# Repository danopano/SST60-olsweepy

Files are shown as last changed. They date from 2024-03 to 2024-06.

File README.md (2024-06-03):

# SST60-olsweepy
This repo is a fork and mod of dededecline/SST60! Below renders are from his original design.  
The provided production files cover daughterboard variants with and without flex cuts.  
Kicad 8.0 is recommended, with the JLC PCB plugin installed.  

## Fully open source multi-layout 60% PCB
Render1
Render2
<sub> renders outdated, using the old outline. </sub>

## Layout support
KLE

## Features
- RGB Underglow
- RP2040 processor
- MX and Alps compatible
- Indicator light positions for Caps Lock and Esc
- Standard tray mount support
- Gummy O-Ring support (Bakenko, ogre, etc. anything that h60 supports, this does too.)
- USB-C or Unified Daughterboard (or equivalent with the same pinout)
- Overcurrent and ESD protection
- Flex meme cuts

## ***DISCLAIMER***
Note: the below claim is not yet applicable for this fork.
This PCB has been tested and confirmed to work properly. The members of the PCB development team are not liable if you end up with a non-functional pcb. Order at your own risk. Support will not be provided but pull requests will be reviewed and possibly accepted.

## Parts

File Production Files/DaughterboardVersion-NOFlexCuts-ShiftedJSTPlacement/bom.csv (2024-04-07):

Designator | Footprint | Quantity | Value | LCSC Part #
C_1V-Decoup1, C_3V-Decoup2, C_LDO1, C_LDO2 | 0402 | 4 | 1u
C_1V-Decoup2, C_1V-Decoup3, C_3V-Decoup3, C_3V-Decoup4, C_3V-Decoup5, C_3V-Decoup6, C_3V-Decoup7, C_3V-Decoup8, C_3V-Decoup9, C_Flash1 | 0402 | 10 | 100n
C_3V-Decoup1 | 0402 | 1 | 10u
C_Crystal1, C_Crystal2 | 0402 | 2 | 22pF
C_Shield1 | 0402 | 1 | 4.7n
D1, D10, D11, D12, D13, D14, D15, D16, D17, D18, D19, D2, D20, D21, D22, D23, D25, D26, D27, D28, D3, D30, D31, D32, D33, D34, D35, D36, D37, D38, D39, D4, D40, D41, D42, D43, D44, D45, D46, D48, D49, D5, D50, D51, D53, D54, D55, D56, D57, D58, D59, D6, D61, D62, D63, D64, D65, D66, D67, D68, D7, D8 | D_SOD-123 | 62 | 1N4148
D69, D70, D71, D72, D73, D74, D75, D76, D77, D78, D79, D80, D81, D82, D83, D84 | LED_WS2812_2020 | 16 | WS2812B-2020
F1 | 0805 | 1 | 500mA
J1 | JST_SH_SM04B-SRSS-TB_1x04-1MP_P1.00mm_Horizontal | 1 | SM04B-SRSS-TB(LF)(SN)
R_Crystal1, R_Flash1, R_RST1 | 0402 | 3 | 1k
R_DATA1, R_DATA2 | 0402 | 2 | 27
R_LED1, R_LED2 | 0402 | 2 | 220
R_Shield1 | 0402 | 1 | 1M
SW1, SW2 | SW_SPST_TL3342 | 2 | TL3342F450QG
U1 | RP2040-QFN-56 | 1 | RP2040
U2 | SOIC-8_5.23x5.23mm_P1.27mm | 1 | W25Q128JVS
U3 | SOT-23 | 1 | XC6206PxxxMR
U4 | SOT143B | 1 | PRTR5V0U2X
U5 | SOT-23-5 | 1 | 74AHCT1G125
Y1 | Crystal_SMD_3225-4Pin_3.2x2.5mm | 1 | 12MHz

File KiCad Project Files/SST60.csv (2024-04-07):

Id | Designator | Footprint | Quantity | Designation | Supplier and ref
1 | MX7,MX4,MX62,MX17,MX74,MX76 | MXOnly-1.5U-NoLED | 6 | MX-NoLED
2 | MX28,MX59,MX23,MX50,MX15,MX36,MX35,MX20,MX39,MX16,MX75,MX14,MX58,MX30,MX21,MX67,MX27,MX29,MX55,MX43,MX54,MX9,MX8,MX34,MX64,MX47,MX56,MX25,MX19,MX10,MX73,MX53,MX49,MX44,MX46,MX61,MX24,MX12,MX40,MX18,MX33,MX60,MX63,MX69,MX45,MX13,MX37,MX48,MX22,MX38 | MXOnly-1U-NoLED | 50 | MX-NoLED
3 | MX1 | MXOnly-1.25U | 1 | MX-LED
4 | MX66 | MXOnly-1.75U-NoLED | 1 | MX-NoLED
5 | H1 | L60 Outline | 1 | PCB Outline
6 | MX70,MX6 | MXOnly-2.25U-NoLED | 2 | MX-NoLED
7 | MX3 | MXOnly-1U | 1 | MX-LED
8 | MX42 | MXOnly-7U-ReversedStabilizers-NoLED | 1 | MX-NoLED
9 | U4 | SOT143B | 1 | PRTR5V0U2X
10 | SW2 | SW_SPST_TL3342 | 1 | Reset
11 | D19,D46,D15,D63,D35,D26,D54,D34,D50,D48,D22,D40,D14,D10,D61,D37,D39,D2,D6,D1,D67,D13,D21,D4,D3,D36,D12,D25,D30,D51,D28,D38,D45,D32,D55,D49,D5,D23,D20,D42,D64,D65,D16,D56,D27,D59,D58,D57,D43,D68,D66,D62,D18,D33,D8,D44,D53,D7,D31,D11,D41,D17 | D_SOD-123 | 62 | D_Small
12 | C_3V-Decoup8,C_1V-Decoup2,C_Flash1,C_3V-Decoup6,C_3V-Decoup7,C_3V-Decoup4,C_3V-Decoup5,C_3V-Decoup3,C_1V-Decoup3,C_3V-Decoup9 | C_0402_1005Metric | 10 | .1u
13 | D74,D71,D84,D78,D77,D72,D75,D76,D79,D70,D82,D81,D73,D83,D80,D69 | LED_WS2812_2020 | 16 | WS2812B-2020
14 | C_LDO2,C_3V-Decoup2,C_1V-Decoup1,C_LDO1 | C_0402_1005Metric | 4 | 1u
15 | C_Crystal2,C_Crystal1 | C_0402_1005Metric | 2 | 22pF
16 | R_Crystal1,R_RST1,R_Flash1 | R_0402_1005Metric | 3 | 1k
17 | R_LED1,R_LED2 | R_0402_1005Metric | 2 | 220
18 | USB1 | HRO-TYPE-C-31-M-12-Assembly | 1 | HRO-TYPE-C-31-M-12
19 | U1 | RP2040-QFN-56 | 1 | RP2040
20 | J2 | PinHeader_1x05_P2.54mm_Vertical | 1 | SWD
21 | R_DATA2,R_DATA1 | R_0402_1005Metric | 2 | 27
22 | R_USB1,R_USB2 | R_0402_1005Metric | 2 | 5k1
23 | SW1 | SW_SPST_TL3342 | 1 | Boot
24 | J1 | JST_SH_SM04B-SRSS-TB_1x04-1MP_P1.00mm_Horizontal | 1 | SM04B
25 | R_Shield1 | R_0402_1005Metric | 1 | 1M
26 | Y1 | Crystal_SMD_3225-4Pin_3.2x2.5mm | 1 | 12MHz
27 | U5 | SOT-23-5 | 1 | 74AHCT1G125
28 | U3 | SOT-23 | 1 | XC6206PxxxMR
29 | C_Shield1 | C_0402_1005Metric | 1 | 4.7n
30 | U2 | SOIC-8_5.23x5.23mm_P1.27mm | 1 | W25Q128JVS
31 | F1 | Fuse_0805_2012Metric | 1 | 500mA
32 | C_3V-Decoup1 | C_0402_1005Metric | 1 | 10u

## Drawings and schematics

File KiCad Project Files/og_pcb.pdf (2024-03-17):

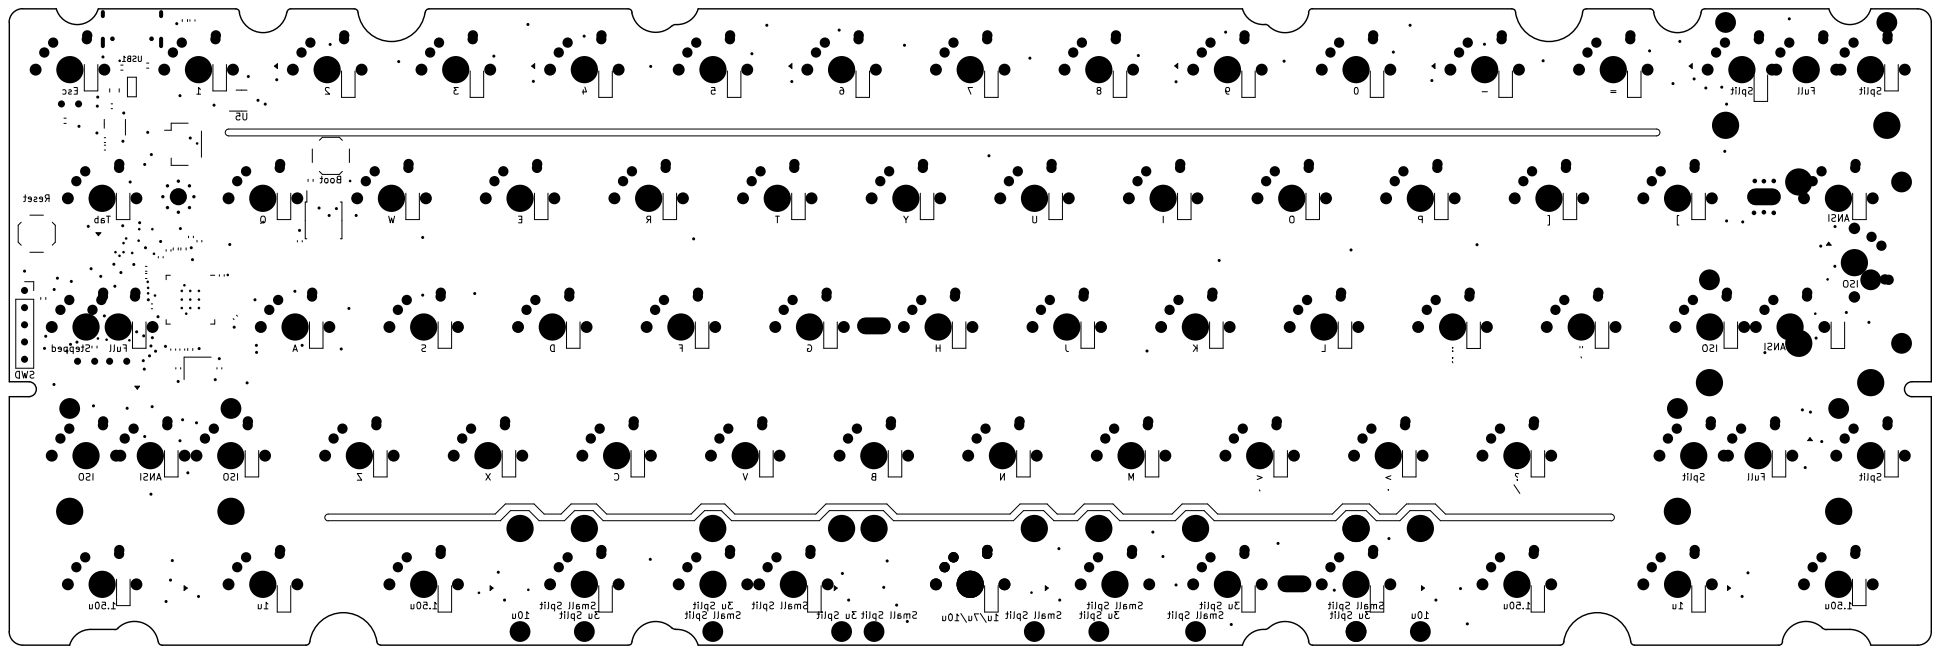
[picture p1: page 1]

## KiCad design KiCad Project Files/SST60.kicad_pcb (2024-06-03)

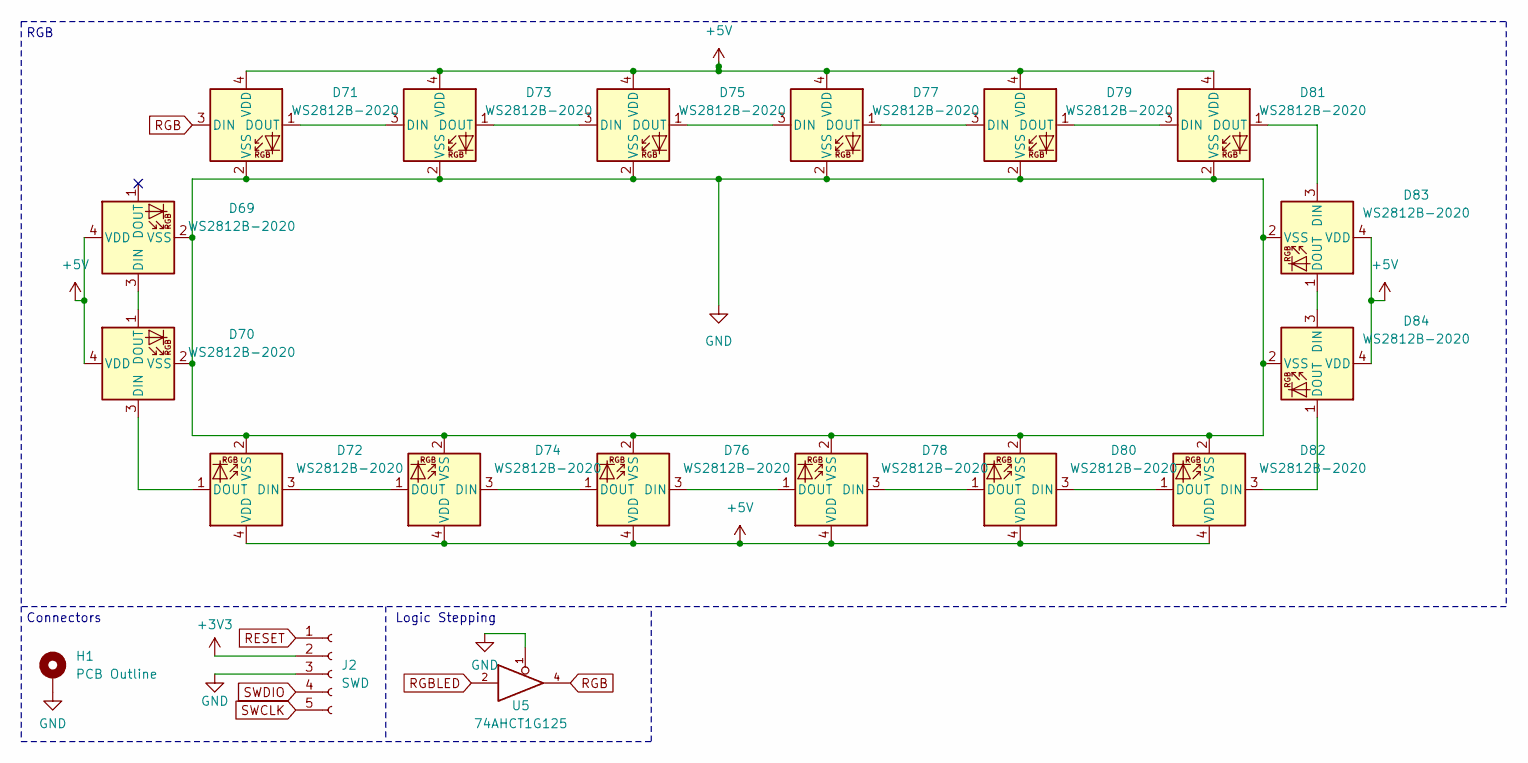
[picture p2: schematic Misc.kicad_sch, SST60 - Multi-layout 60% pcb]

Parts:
D69, D70, D71, D72, D73, D74, D75, D76, D77, D78, D79, D80, D81, D82, D83, D84: WS2812B-2020; LED_WS2812_2020
H1: PCB Outline; L60 Outline
J2: SWD; PinHeader_1x05_P2.54mm_Vertical
U5: 74AHCT1G125; SOT-23-5

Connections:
+3V3: J2.2; also elsewhere on the board
+5V: D69.4 (VDD), D70.4 (VDD), D71.4 (VDD), D72.4 (VDD), D73.4 (VDD), D74.4 (VDD), D75.4 (VDD), D76.4 (VDD), D77.4 (VDD), D78.4 (VDD), D79.4 (VDD), D80.4 (VDD), D81.4 (VDD), D82.4 (VDD), D83.4 (VDD), D84.4 (VDD), U5.5 (+5V); also elsewhere on the board
GND: D69.2 (VSS), D70.2 (VSS), D71.2 (VSS), D72.2 (VSS), D73.2 (VSS), D74.2 (VSS), D75.2 (VSS), D76.2 (VSS), D77.2 (VSS), D78.2 (VSS), D79.2 (VSS), D80.2 (VSS), D81.2 (VSS), D82.2 (VSS), D83.2 (VSS), D84.2 (VSS), H1.1, J2.3, U5.1, U5.3 (GND); also elsewhere on the board
unnamed: D69.3 (DIN), D70.1 (DOUT)
unnamed: D70.3 (DIN), D72.1 (DOUT)
unnamed: D71.1 (DOUT), D73.3 (DIN)
unnamed: D72.3 (DIN), D74.1 (DOUT)
unnamed: D73.1 (DOUT), D75.3 (DIN)
unnamed: D74.3 (DIN), D76.1 (DOUT)
unnamed: D75.1 (DOUT), D77.3 (DIN)
unnamed: D76.3 (DIN), D78.1 (DOUT)
unnamed: D77.1 (DOUT), D79.3 (DIN)
unnamed: D78.3 (DIN), D80.1 (DOUT)
unnamed: D79.1 (DOUT), D81.3 (DIN)
unnamed: D80.3 (DIN), D82.1 (DOUT)
unnamed: D81.1 (DOUT), D83.3 (DIN)
unnamed: D82.3 (DIN), D84.1 (DOUT)
unnamed: D83.1 (DOUT), D84.3 (DIN)
RESET: J2.1; also elsewhere on the board
RGB: D71.3 (DIN), U5.4
RGBLED: U5.2; also elsewhere on the board
SWCLK: J2.5; also elsewhere on the board
SWDIO: J2.4; also elsewhere on the board

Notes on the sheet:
Logic Stepping
Connectors
RGB

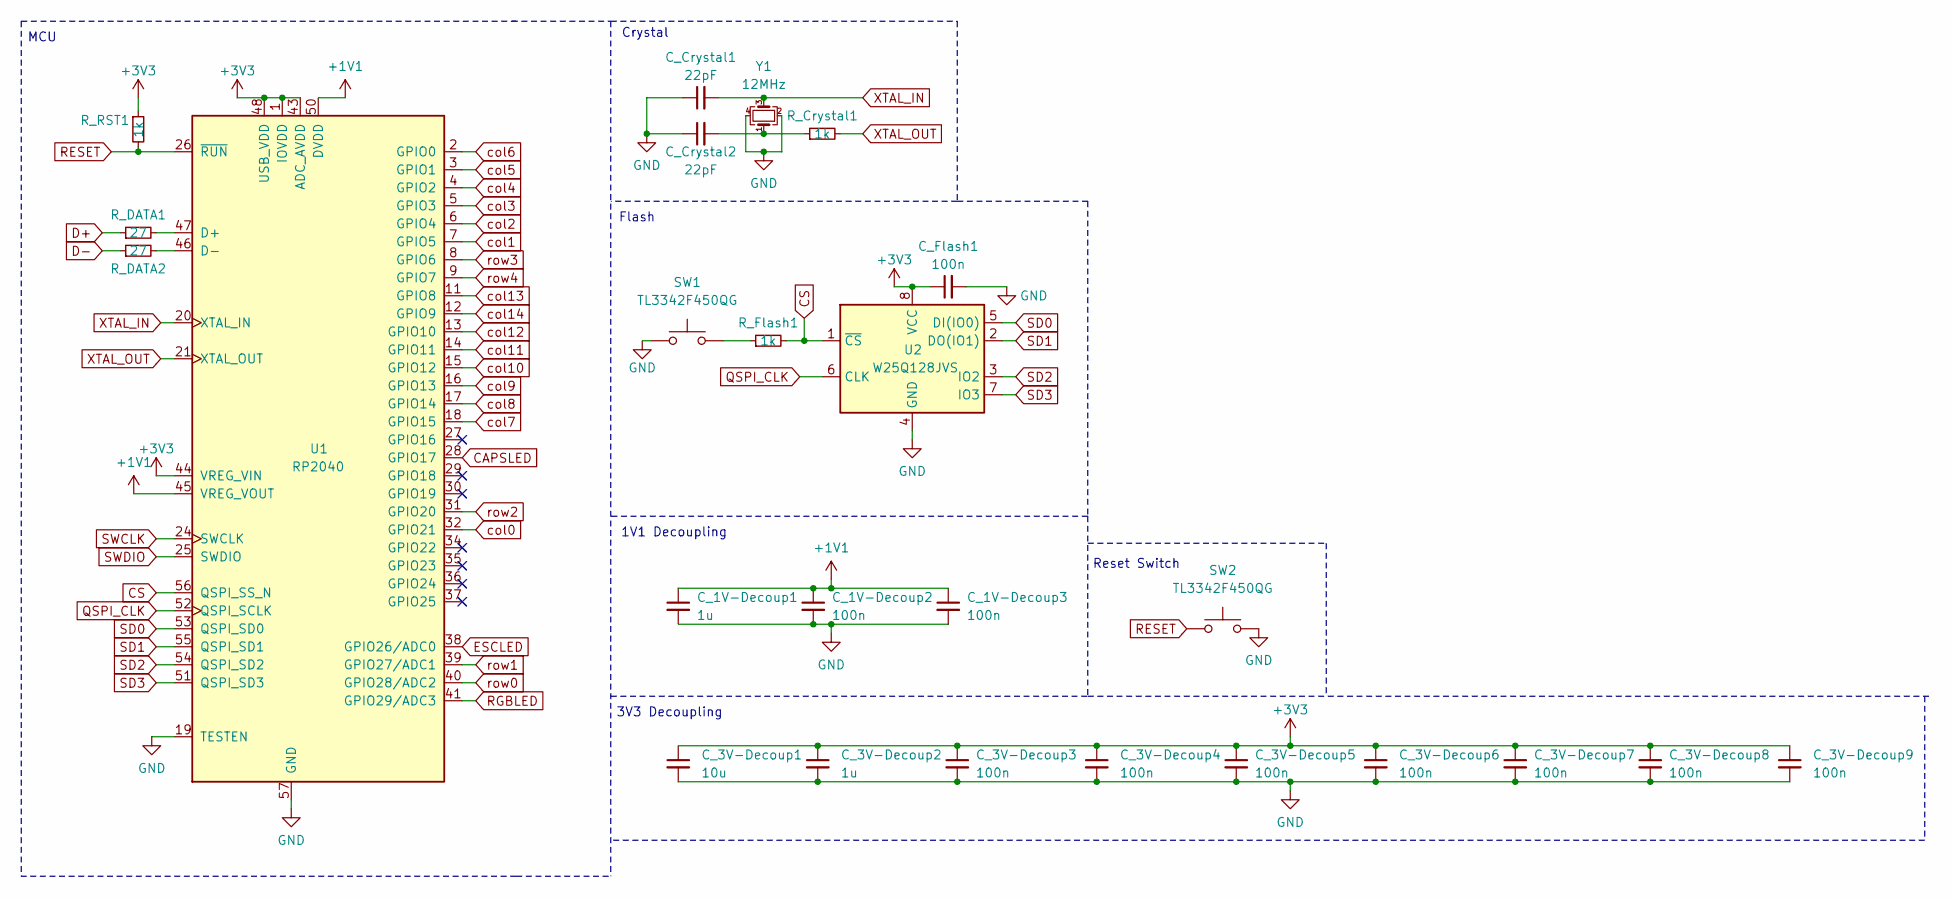
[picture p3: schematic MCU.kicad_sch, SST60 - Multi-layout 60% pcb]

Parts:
C_1V-Decoup1, C_3V-Decoup2: 1u; C_0402_1005Metric
C_1V-Decoup2, C_1V-Decoup3, C_3V-Decoup3, C_3V-Decoup4, C_3V-Decoup5, C_3V-Decoup6, C_3V-Decoup7, C_3V-Decoup8, C_3V-Decoup9: 100n; C_0402_1005Metric
C_3V-Decoup1: 10u; C_0402_1005Metric
C_Crystal1, C_Crystal2: 22pF; C_0402_1005Metric
C_Flash1: 100n; C_0402_1005Metric
R_Crystal1: 1k; R_0402_1005Metric
R_DATA1, R_DATA2: 27; R_0402_1005Metric
R_Flash1: 1k; R_0402_1005Metric
R_RST1: 1k; R_0402_1005Metric
SW1, SW2: TL3342F450QG; SW_SPST_TL3342
U1: RP2040; RP2040-QFN-56
U2: W25Q128JVS; SOIC-8_5.23x5.23mm_P1.27mm
Y1: 12MHz; Crystal_SMD_3225-4Pin_3.2x2.5mm

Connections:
+1V1: C_1V-Decoup1.1, C_1V-Decoup2.1, C_1V-Decoup3.1, U1.23 (DVDD), U1.45 (VREG_VOUT), U1.50 (DVDD)
+3V3: C_3V-Decoup1.1, C_3V-Decoup2.1, C_3V-Decoup3.1, C_3V-Decoup4.1, C_3V-Decoup5.1, C_3V-Decoup6.1, C_3V-Decoup7.1, C_3V-Decoup8.1, C_3V-Decoup9.1, C_Flash1.1, R_RST1.1, U1.1 (IOVDD), U1.10 (IOVDD), U1.22 (IOVDD), U1.33 (IOVDD), U1.42 (IOVDD), U1.43 (ADC_AVDD), U1.44 (VREG_VIN), U1.48 (USB_VDD), U1.49 (IOVDD), U2.8 (VCC); also elsewhere on the board
CAPSLED: U1.28 (GPIO17); also elsewhere on the board
CS: R_Flash1.2, U1.56 (QSPI_SS_N), U2.1 (~CS)
D+: R_DATA1.1; also elsewhere on the board
D-: R_DATA2.1; also elsewhere on the board
ESCLED: U1.38 (GPIO26/ADC0); also elsewhere on the board
GND: C_1V-Decoup1.2, C_1V-Decoup2.2, C_1V-Decoup3.2, C_3V-Decoup1.2, C_3V-Decoup2.2, C_3V-Decoup3.2, C_3V-Decoup4.2, C_3V-Decoup5.2, C_3V-Decoup6.2, C_3V-Decoup7.2, C_3V-Decoup8.2, C_3V-Decoup9.2, C_Crystal1.1, C_Crystal2.1, C_Flash1.2, SW1.1, SW2.2, U1.19 (TESTEN), U1.57 (GND), U2.4 (GND), Y1.2, Y1.4; also elsewhere on the board
unnamed: C_Crystal2.2, R_Crystal1.1, Y1.1
unnamed: R_Flash1.1, SW1.2
unnamed: R_DATA1.2, U1.47 (D+)
unnamed: R_DATA2.2, U1.46 (D-)
QSPI_CLK: U1.52 (QSPI_SCLK), U2.6 (CLK)
RESET: R_RST1.2, SW2.1, U1.26 (~RUN); also elsewhere on the board
RGBLED: U1.41 (GPIO29/ADC3); also elsewhere on the board
SD0: U1.53 (QSPI_SD0), U2.5 (DI(IO0))
SD1: U1.55 (QSPI_SD1), U2.2 (DO(IO1))
SD2: U1.54 (QSPI_SD2), U2.3 (IO2)
SD3: U1.51 (QSPI_SD3), U2.7 (IO3)
SWCLK: U1.24 (SWCLK); also elsewhere on the board
SWDIO: U1.25 (SWDIO); also elsewhere on the board
XTAL_IN: C_Crystal1.2, U1.20 (XTAL_IN), Y1.3
XTAL_OUT: R_Crystal1.2, U1.21 (XTAL_OUT)
col0: U1.32 (GPIO21); also elsewhere on the board
col1: U1.7 (GPIO5); also elsewhere on the board
col2: U1.6 (GPIO4); also elsewhere on the board
col3: U1.5 (GPIO3); also elsewhere on the board
col4: U1.4 (GPIO2); also elsewhere on the board
col5: U1.3 (GPIO1); also elsewhere on the board
col6: U1.2 (GPIO0); also elsewhere on the board
col7: U1.18 (GPIO15); also elsewhere on the board
col8: U1.17 (GPIO14); also elsewhere on the board
col9: U1.16 (GPIO13); also elsewhere on the board
col10: U1.15 (GPIO12); also elsewhere on the board
col11: U1.14 (GPIO11); also elsewhere on the board
col12: U1.13 (GPIO10); also elsewhere on the board
col13: U1.11 (GPIO8); also elsewhere on the board
col14: U1.12 (GPIO9); also elsewhere on the board
row0: U1.40 (GPIO28/ADC2); also elsewhere on the board
row1: U1.39 (GPIO27/ADC1); also elsewhere on the board
row2: U1.31 (GPIO20); also elsewhere on the board
row3: U1.8 (GPIO6); also elsewhere on the board
row4: U1.9 (GPIO7); also elsewhere on the board

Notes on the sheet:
Reset Switch
Flash
MCU
Crystal
3V3 Decoupling
1V1 Decoupling

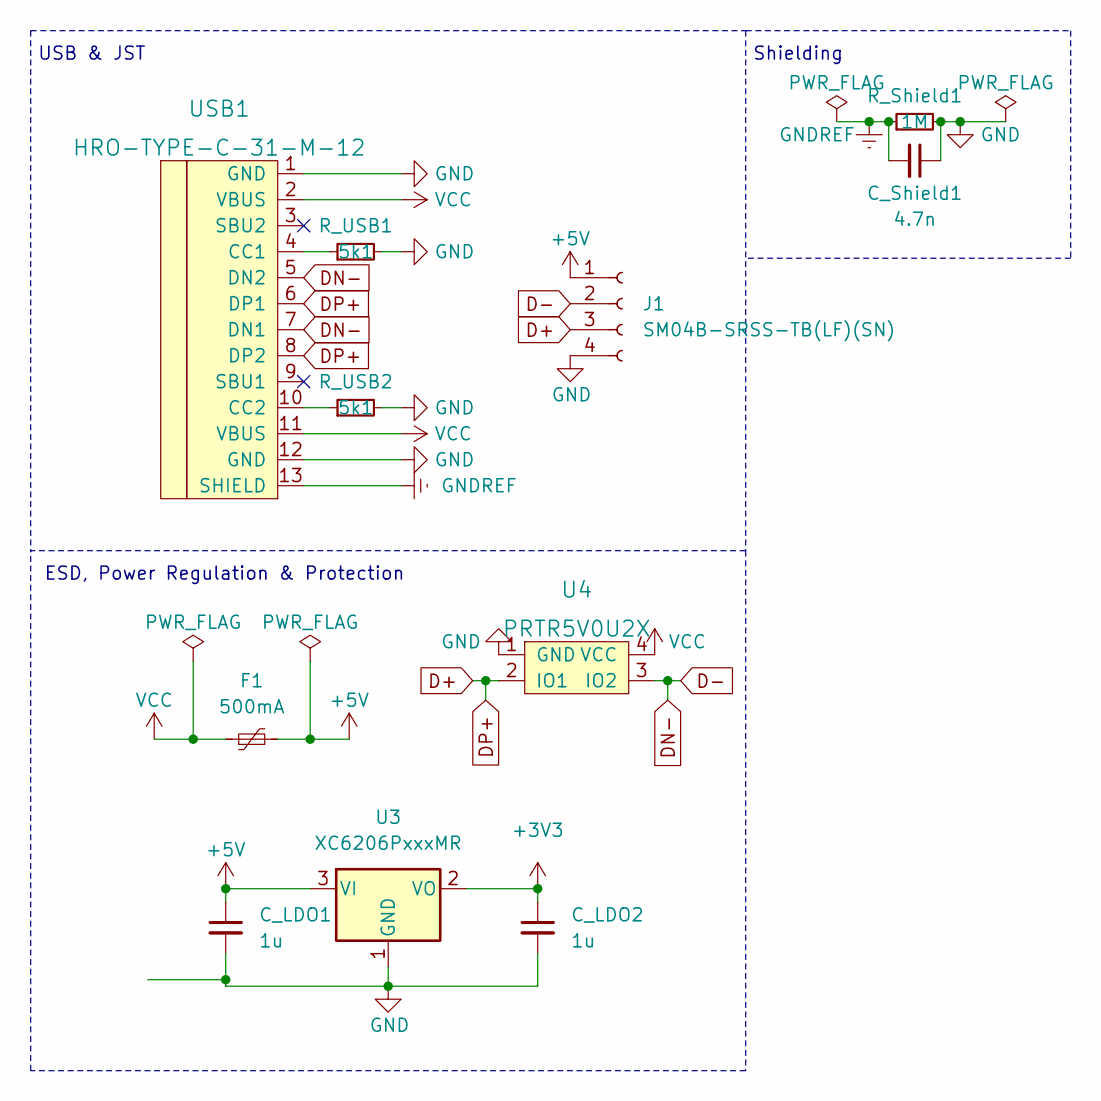
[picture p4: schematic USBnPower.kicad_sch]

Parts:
C_LDO1, C_LDO2: 1u; C_0402_1005Metric
C_Shield1: 4.7n; C_0402_1005Metric
F1: 500mA; Fuse_0805_2012Metric
J1: SM04B-SRSS-TB(LF)(SN); JST_SH_SM04B-SRSS-TB_1x04-1MP_P1.00mm_Horizontal
R_Shield1: 1M; R_0402_1005Metric
R_USB1, R_USB2: 5k1; R_0402_1005Metric
U3: XC6206PxxxMR; SOT-23
U4: PRTR5V0U2X; SOT143B
USB1: HRO-TYPE-C-31-M-12; HRO-TYPE-C-31-M-12-Assembly

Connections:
+3V3: C_LDO2.1, U3.2 (VO); also elsewhere on the board
+5V: C_LDO1.1, F1.2, J1.1, U3.3 (VI); also elsewhere on the board
D+: J1.3, U4.2 (IO1), USB1.6 (DP1), USB1.8 (DP2); also elsewhere on the board
D-: J1.2, U4.3 (IO2), USB1.5 (DN2), USB1.7 (DN1); also elsewhere on the board
GND: C_LDO1.2, C_LDO2.2, C_Shield1.1, J1.4, R_Shield1.2, R_USB1.2, R_USB2.2, U3.1 (GND), U4.1 (GND), USB1.1 (GND), USB1.12 (GND); also elsewhere on the board
GNDREF: C_Shield1.2, R_Shield1.1, USB1.13 (SHIELD)
unnamed: R_USB1.1, USB1.4 (CC1)
unnamed: R_USB2.1, USB1.10 (CC2)
VCC: F1.1, U4.4 (VCC), USB1.2 (VBUS), USB1.11 (VBUS)

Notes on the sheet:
Shielding
ESD, Power Regulation & Protection
USB & JST

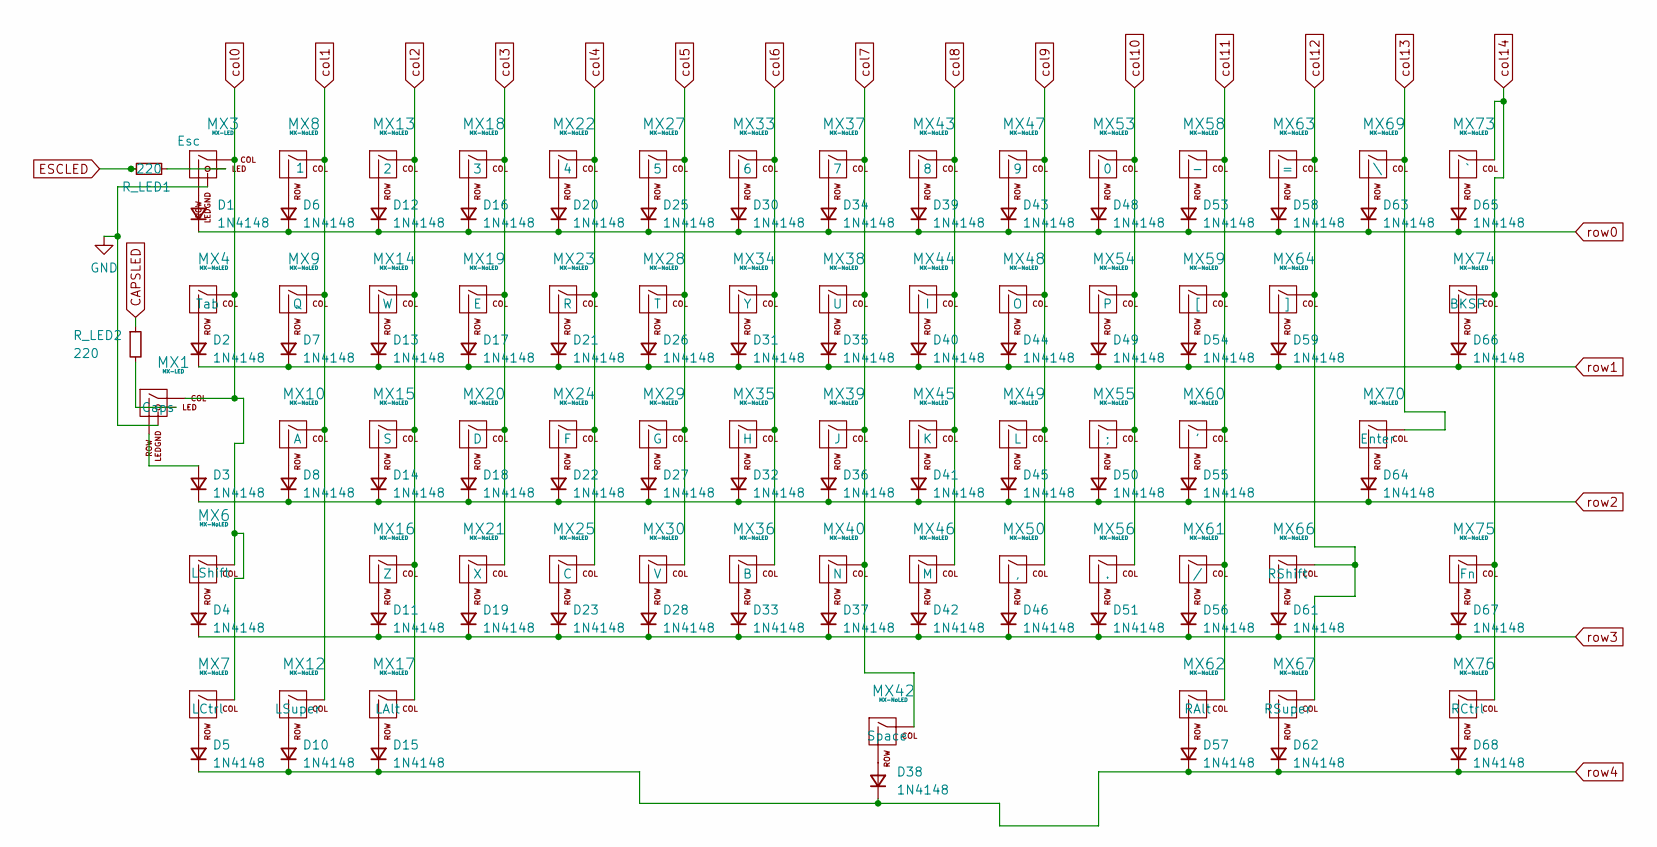
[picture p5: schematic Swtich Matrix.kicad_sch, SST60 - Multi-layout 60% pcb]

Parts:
D1, D2, D3, D4, D5, D6, D7, D8, D10, D11, D12, D13, D14, D15, D16, D17, D18, D19, D20, D21, D22, D23, D25, D26, D27, D28, D30, D31, D32, D33, D34, D35, D36, D37, D38, D39, D40, D41, D42, D43, D44, D45, D46, D48, D49, D50, D51, D53, D54, D55, D56, D57, D58, D59, D61, D62, D63, D64, D65, D66, D67, D68: 1N4148; D_SOD-123
MX1: MX-LED; MXOnly-1.25U
MX3: MX-LED; MXOnly-1U
MX4, MX7, MX17, MX62, MX74, MX76: MX-NoLED; MXOnly-1.5U-NoLED
MX6, MX70: MX-NoLED; MXOnly-2.25U-NoLED
MX8, MX9, MX10, MX12, MX13, MX14, MX15, MX16, MX18, MX19, MX20, MX21, MX22, MX23, MX24, MX25, MX27, MX28, MX29, MX30, MX33, MX34, MX35, MX36, MX37, MX38, MX39, MX40, MX43, MX44, MX45, MX46, MX47, MX48, MX49, MX50, MX53, MX54, MX55, MX56, MX58, MX59, MX60, MX61, MX63, MX64, MX67, MX69, MX73, MX75: MX-NoLED; MXOnly-1U-NoLED
MX42: MX-NoLED; MXOnly-7U-ReversedStabilizers-NoLED
MX66: MX-NoLED; MXOnly-1.75U-NoLED
R_LED1, R_LED2: 220; R_0402_1005Metric

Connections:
CAPSLED: R_LED2.1; also elsewhere on the board
ESCLED: R_LED1.1; also elsewhere on the board
GND: MX1.4 (LEDGND), MX3.4 (LEDGND); also elsewhere on the board
unnamed: D1.2 (A), MX3.2 (ROW)
unnamed: D2.2 (A), MX4.2 (ROW)
unnamed: D3.2 (A), MX1.2 (ROW)
unnamed: D4.2 (A), MX6.2 (ROW)
unnamed: D5.2 (A), MX7.2 (ROW)
unnamed: D6.2 (A), MX8.2 (ROW)
unnamed: D7.2 (A), MX9.2 (ROW)
unnamed: D8.2 (A), MX10.2 (ROW)
unnamed: D10.2 (A), MX12.2 (ROW)
unnamed: D11.2 (A), MX16.2 (ROW)
unnamed: D12.2 (A), MX13.2 (ROW)
unnamed: D13.2 (A), MX14.2 (ROW)
unnamed: D14.2 (A), MX15.2 (ROW)
unnamed: D15.2 (A), MX17.2 (ROW)
unnamed: D16.2 (A), MX18.2 (ROW)
unnamed: D17.2 (A), MX19.2 (ROW)
unnamed: D18.2 (A), MX20.2 (ROW)
unnamed: D19.2 (A), MX21.2 (ROW)
unnamed: D20.2 (A), MX22.2 (ROW)
unnamed: D21.2 (A), MX23.2 (ROW)
unnamed: D22.2 (A), MX24.2 (ROW)
unnamed: D23.2 (A), MX25.2 (ROW)
unnamed: D25.2 (A), MX27.2 (ROW)
unnamed: D26.2 (A), MX28.2 (ROW)
unnamed: D27.2 (A), MX29.2 (ROW)
unnamed: D28.2 (A), MX30.2 (ROW)
unnamed: D30.2 (A), MX33.2 (ROW)
unnamed: D31.2 (A), MX34.2 (ROW)
unnamed: D32.2 (A), MX35.2 (ROW)
unnamed: D33.2 (A), MX36.2 (ROW)
unnamed: D34.2 (A), MX37.2 (ROW)
unnamed: D35.2 (A), MX38.2 (ROW)
unnamed: D36.2 (A), MX39.2 (ROW)
unnamed: D37.2 (A), MX40.2 (ROW)
unnamed: D38.2 (A), MX42.2 (ROW)
unnamed: D39.2 (A), MX43.2 (ROW)
unnamed: D40.2 (A), MX44.2 (ROW)
unnamed: D41.2 (A), MX45.2 (ROW)
unnamed: D42.2 (A), MX46.2 (ROW)
unnamed: D43.2 (A), MX47.2 (ROW)
unnamed: D44.2 (A), MX48.2 (ROW)
unnamed: D45.2 (A), MX49.2 (ROW)
unnamed: D46.2 (A), MX50.2 (ROW)
unnamed: D48.2 (A), MX53.2 (ROW)
unnamed: D49.2 (A), MX54.2 (ROW)
unnamed: D50.2 (A), MX55.2 (ROW)
unnamed: D51.2 (A), MX56.2 (ROW)
unnamed: D53.2 (A), MX58.2 (ROW)
unnamed: D54.2 (A), MX59.2 (ROW)
unnamed: D55.2 (A), MX60.2 (ROW)
unnamed: D56.2 (A), MX61.2 (ROW)
unnamed: D57.2 (A), MX62.2 (ROW)
unnamed: D58.2 (A), MX63.2 (ROW)
unnamed: D59.2 (A), MX64.2 (ROW)
unnamed: D61.2 (A), MX66.2 (ROW)
unnamed: D62.2 (A), MX67.2 (ROW)
unnamed: D63.2 (A), MX69.2 (ROW)
unnamed: D64.2 (A), MX70.2 (ROW)
unnamed: D65.2 (A), MX73.2 (ROW)
unnamed: D66.2 (A), MX74.2 (ROW)
unnamed: D67.2 (A), MX75.2 (ROW)
unnamed: D68.2 (A), MX76.2 (ROW)
unnamed: MX1.3 (LED), R_LED2.2
unnamed: MX3.3 (LED), R_LED1.2
col0: MX1.1 (COL), MX3.1 (COL), MX4.1 (COL), MX6.1 (COL), MX7.1 (COL); also elsewhere on the board
col1: MX8.1 (COL), MX9.1 (COL), MX10.1 (COL), MX12.1 (COL); also elsewhere on the board
col2: MX13.1 (COL), MX14.1 (COL), MX15.1 (COL), MX16.1 (COL), MX17.1 (COL); also elsewhere on the board
col3: MX18.1 (COL), MX19.1 (COL), MX20.1 (COL), MX21.1 (COL); also elsewhere on the board
col4: MX22.1 (COL), MX23.1 (COL), MX24.1 (COL), MX25.1 (COL); also elsewhere on the board
col5: MX27.1 (COL), MX28.1 (COL), MX29.1 (COL), MX30.1 (COL); also elsewhere on the board
col6: MX33.1 (COL), MX34.1 (COL), MX35.1 (COL), MX36.1 (COL); also elsewhere on the board
col7: MX37.1 (COL), MX38.1 (COL), MX39.1 (COL), MX40.1 (COL), MX42.1 (COL); also elsewhere on the board
col8: MX43.1 (COL), MX44.1 (COL), MX45.1 (COL), MX46.1 (COL); also elsewhere on the board
col9: MX47.1 (COL), MX48.1 (COL), MX49.1 (COL), MX50.1 (COL); also elsewhere on the board
col10: MX53.1 (COL), MX54.1 (COL), MX55.1 (COL), MX56.1 (COL); also elsewhere on the board
col11: MX58.1 (COL), MX59.1 (COL), MX60.1 (COL), MX61.1 (COL), MX62.1 (COL); also elsewhere on the board
col12: MX63.1 (COL), MX64.1 (COL), MX66.1 (COL), MX67.1 (COL); also elsewhere on the board
col13: MX69.1 (COL), MX70.1 (COL); also elsewhere on the board
col14: MX73.1 (COL), MX74.1 (COL), MX75.1 (COL), MX76.1 (COL); also elsewhere on the board
row0: D1.1 (K), D6.1 (K), D12.1 (K), D16.1 (K), D20.1 (K), D25.1 (K), D30.1 (K), D34.1 (K), D39.1 (K), D43.1 (K), D48.1 (K), D53.1 (K), D58.1 (K), D63.1 (K), D65.1 (K); also elsewhere on the board
row1: D2.1 (K), D7.1 (K), D13.1 (K), D17.1 (K), D21.1 (K), D26.1 (K), D31.1 (K), D35.1 (K), D40.1 (K), D44.1 (K), D49.1 (K), D54.1 (K), D59.1 (K), D66.1 (K); also elsewhere on the board
row2: D3.1 (K), D8.1 (K), D14.1 (K), D18.1 (K), D22.1 (K), D27.1 (K), D32.1 (K), D36.1 (K), D41.1 (K), D45.1 (K), D50.1 (K), D55.1 (K), D64.1 (K); also elsewhere on the board
row3: D4.1 (K), D11.1 (K), D19.1 (K), D23.1 (K), D28.1 (K), D33.1 (K), D37.1 (K), D42.1 (K), D46.1 (K), D51.1 (K), D56.1 (K), D61.1 (K), D67.1 (K); also elsewhere on the board
row4: D5.1 (K), D10.1 (K), D15.1 (K), D38.1 (K), D57.1 (K), D62.1 (K), D68.1 (K); also elsewhere on the board

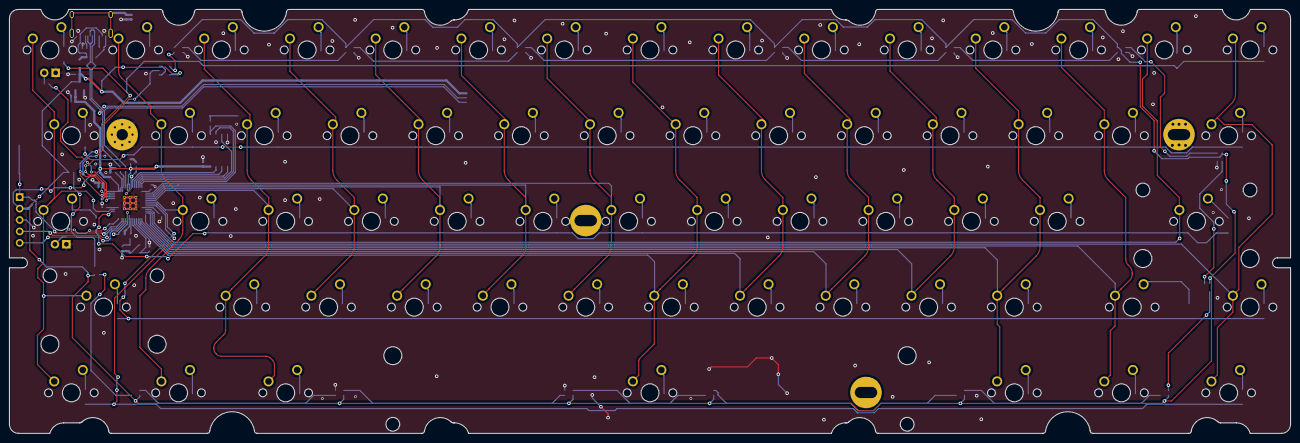
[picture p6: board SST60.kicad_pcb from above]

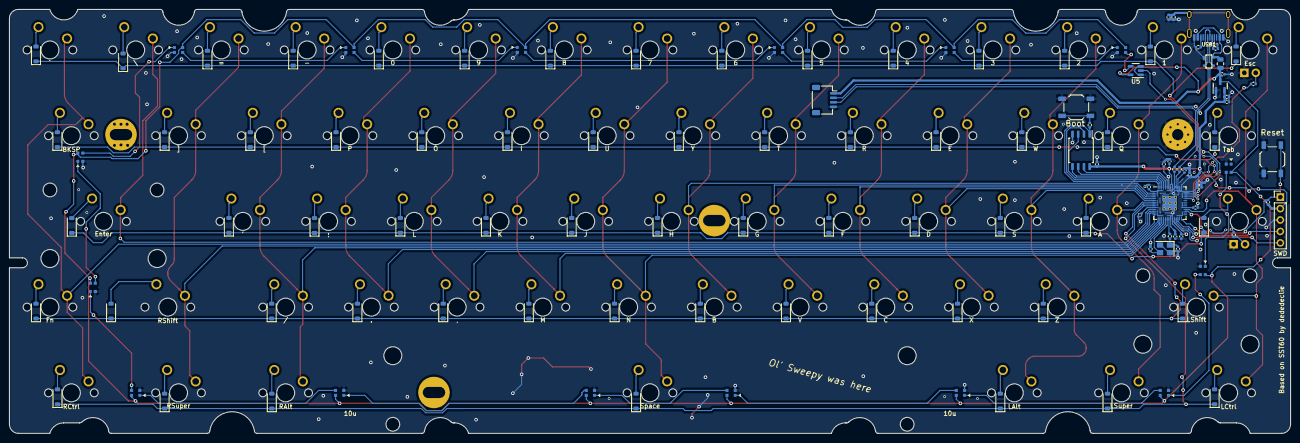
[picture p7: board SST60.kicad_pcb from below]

Board: 2 copper layers, 284.7 x 94.2 mm, 181 parts (118 on the bottom side), 128 nets.

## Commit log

2024-03-17 Initial Modifications
    Summary of changes from original SST60:
    -Removes extraneous keys, opting for ANSI-only, split right shift, split Backspace, 7U space bar, stepped caps lock.
    -Switched from MX-ANSI hybrid to MX-only
    [MCU.kicad_sch, Misc.kicad_sch, SST60.kicad_sch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]
2024-03-24 Error Cleanup
    Resolved all errors in sch, and most errors in pcb, except "intentional" ones concerning H1.
    Will readdress rule changes and violations once attempting to submit to fab house.
    [MCU.kicad_sch, SST60.kicad_pcb, USBnPower.kicad_sch]
2024-04-07 Component updates
    Updates to components to facilitate JLC PCB process.
    [MCU.kicad_sch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]
2024-04-07 Further Component Updates
    More updating of components to decide what is and isn't included in output BOM and Placement files, as well as other component values, to smooth out wrinkles with JLC PCB process.
    [Misc.kicad_sch, SST60.kicad_pcb, USBnPower.kicad_sch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]
2024-04-07 Two sets of production files
    Made two distinct sets of production files: DaughterboardVersion-NOFlexCuts and DaughterboardVersion-WITHFlexCuts.
    Should be ready to order, once reviewed.
    [SST60.kicad_pcb, SST60HS-BOM.csv, SST60HS.kicad_pcb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]
2024-06-03 Shifted JST
    This update shifts the JST connected to be placed similar to another reference keyboard, to accommodate a custom milled enclosure - also removes flex cuts -- this is now the default project file design, but older valid production exports are still stored.
    [SST60.kicad_pcb, bom.csv, designators.csv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]
